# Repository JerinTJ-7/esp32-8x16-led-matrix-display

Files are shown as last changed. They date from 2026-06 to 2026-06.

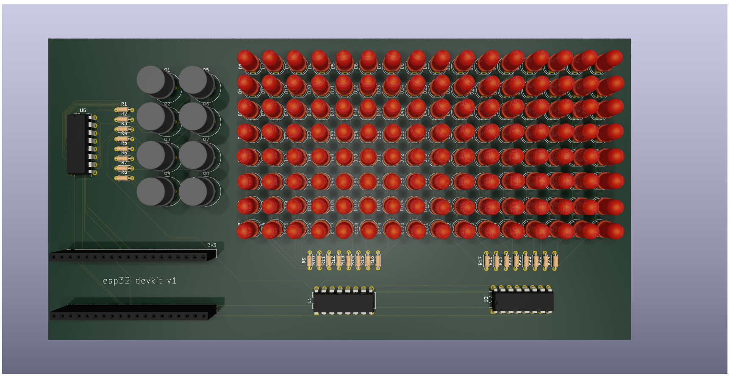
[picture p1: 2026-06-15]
Images/led display pcb2.png

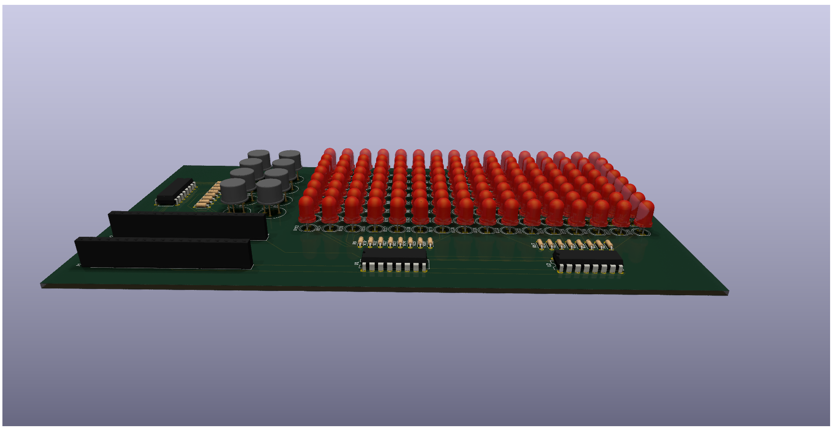
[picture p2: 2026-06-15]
Images/led display pcb3.png

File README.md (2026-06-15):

# ESP32 8×16 LED Matrix Display Board

## Overview

This project is a custom PCB-based LED matrix display designed using KiCad.

The system uses:
- ESP32 DevKit V1
- 74HC595 Shift Registers
- LED Matrix (8×16)
- Blynk IoT
- Wokwi Simulation

## Features

- Text display
- Scrolling messages
- Wi-Fi connectivity
- Mobile control using Blynk
- Custom KiCad PCB

## Tools Used

- KiCad 9
- Arduino IDE
- Wokwi Simulator
- Blynk IoT

## Images
led display pcb

## Files

- KiCad Design Files
- Gerbers
- BOM
- Arduino Firmware
- Project Report

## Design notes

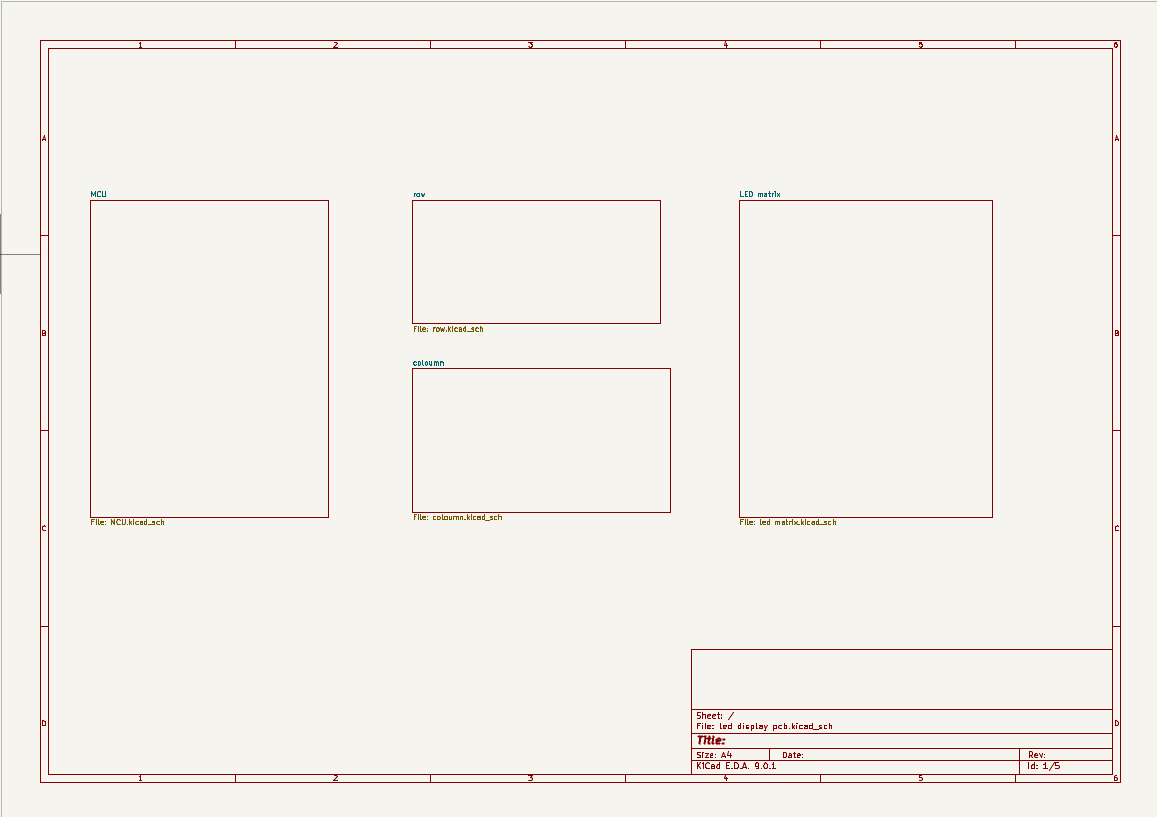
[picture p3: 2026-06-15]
Images/schematic.png

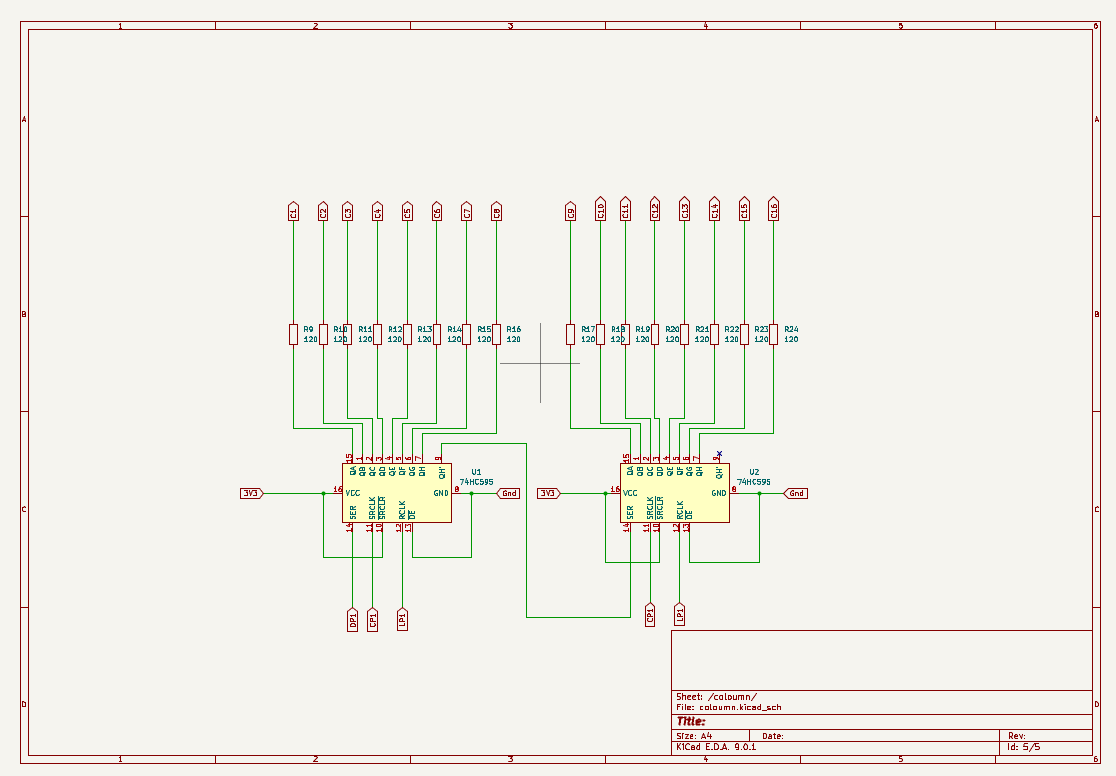
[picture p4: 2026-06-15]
Images/schematic_column.png

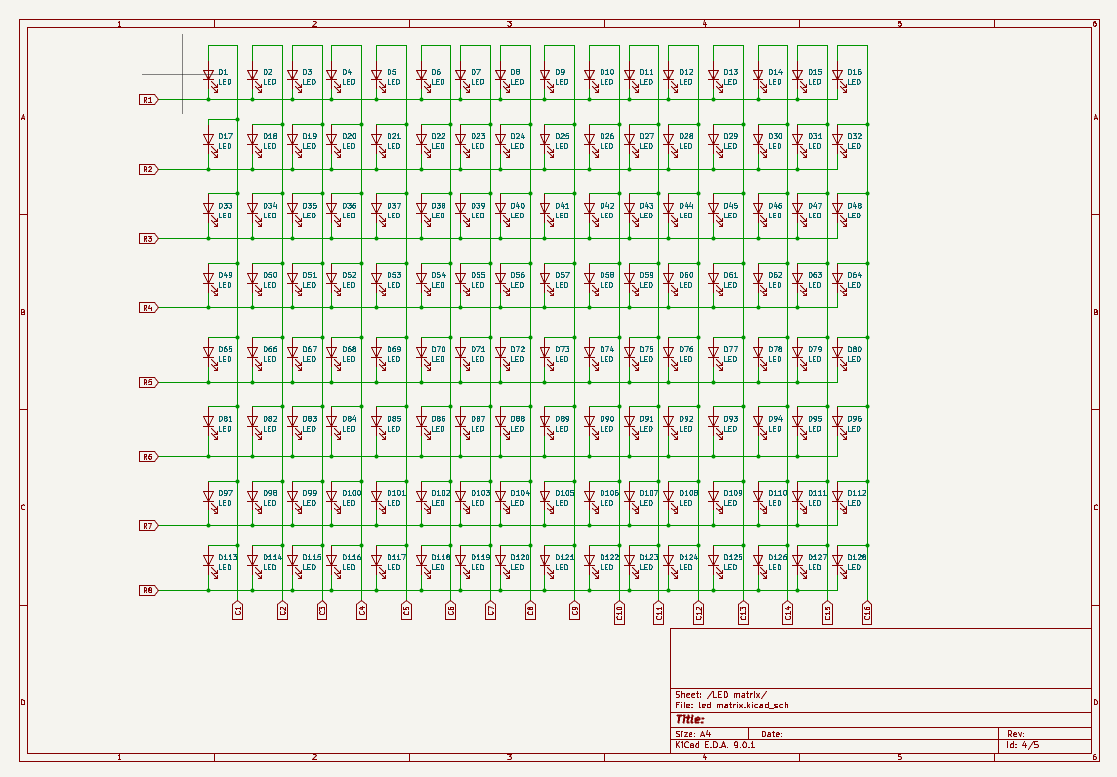
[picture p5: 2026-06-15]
Images/schematic_LED Matrix.png

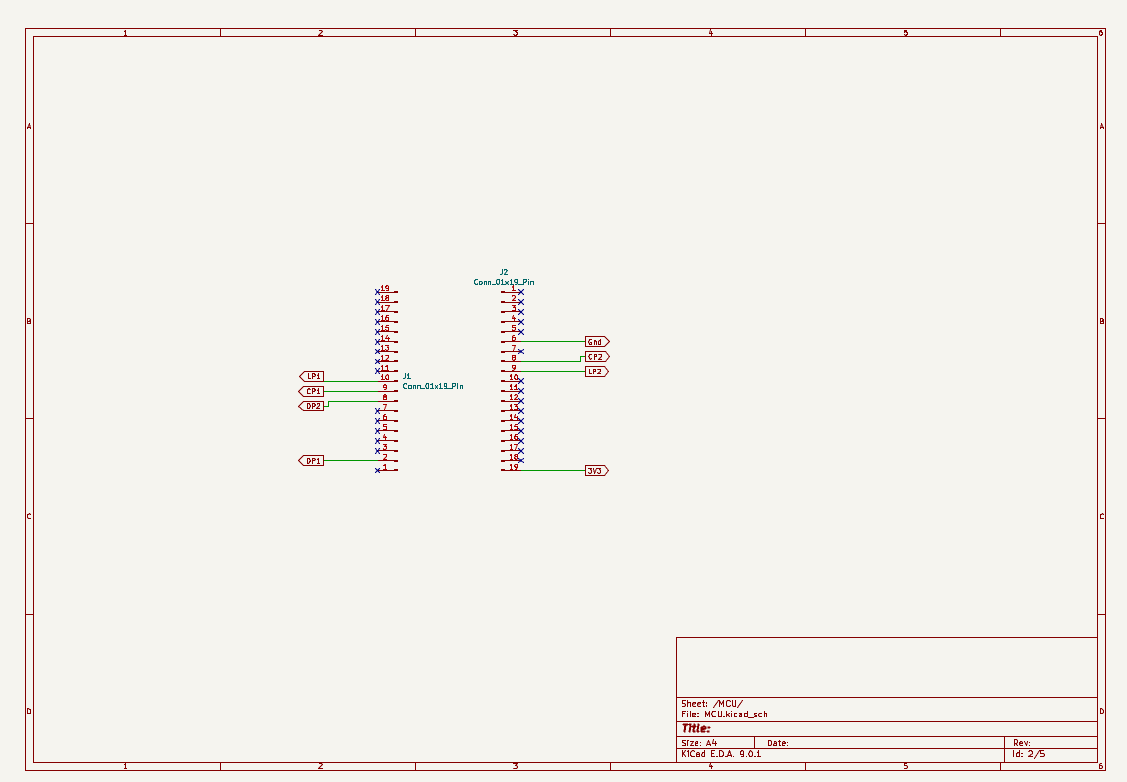
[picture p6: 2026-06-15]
Images/schematic_mcu.png

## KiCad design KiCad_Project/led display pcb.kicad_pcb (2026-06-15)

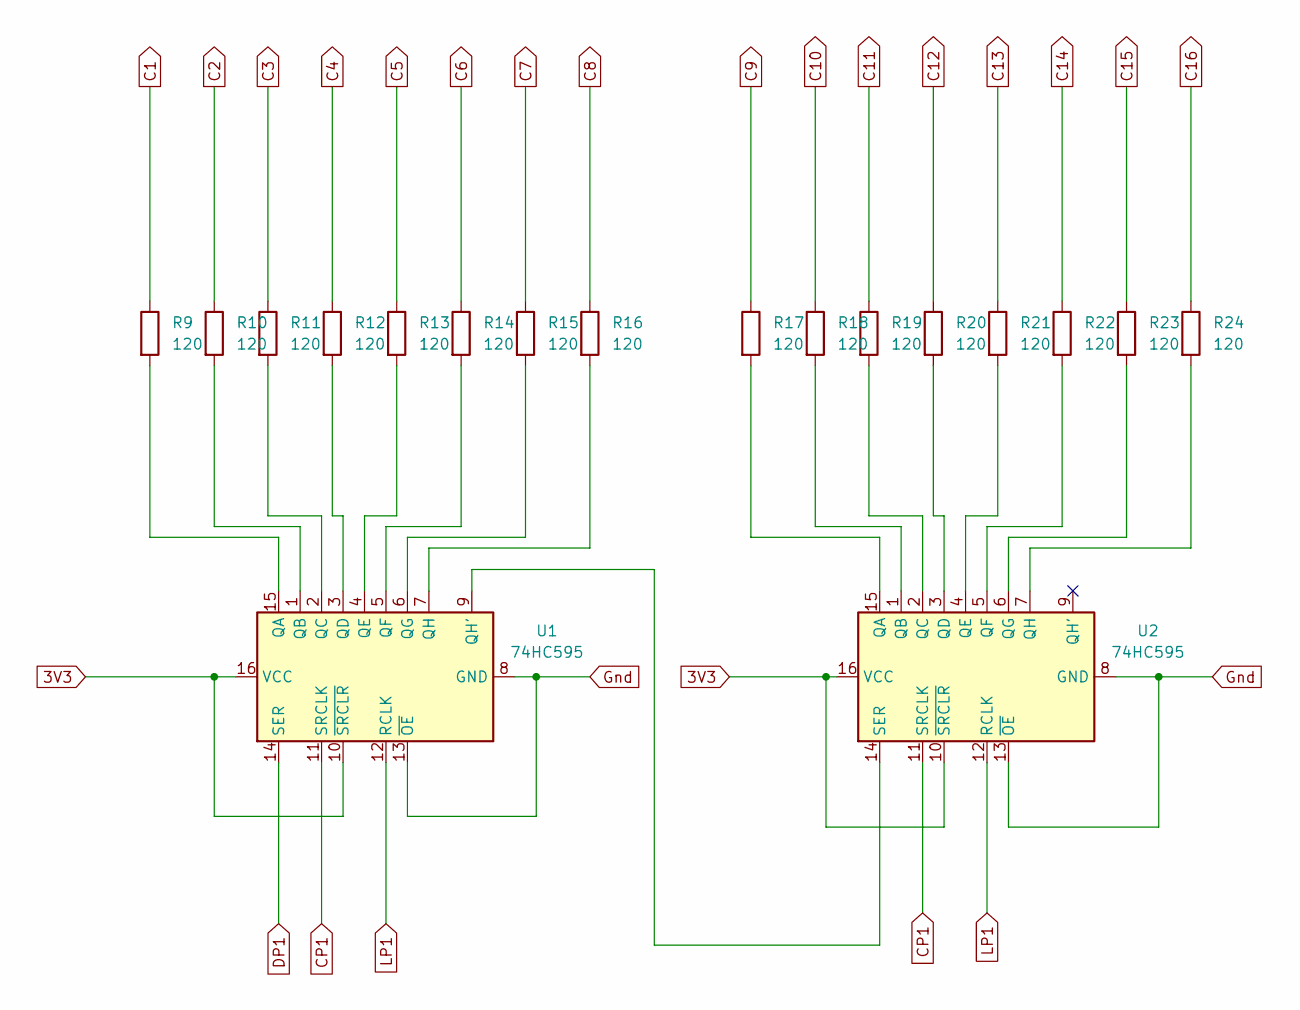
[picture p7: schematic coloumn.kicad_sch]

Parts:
R9, R10, R11, R12, R13, R14, R15, R16, R17, R18, R19, R20, R21, R22, R23, R24: 120; R_Axial_DIN0204_L3.6mm_D1.6mm_P5.08mm_Horizontal
U1, U2: 74HC595; DIP-16_W7.62mm

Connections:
3V3: U1.10 (~SRCLR), U1.16 (VCC), U2.10 (~SRCLR), U2.16 (VCC); also elsewhere on the board
C1: R9.1; also elsewhere on the board
C2: R10.1; also elsewhere on the board
C3: R11.1; also elsewhere on the board
C4: R12.1; also elsewhere on the board
C5: R13.1; also elsewhere on the board
C6: R14.1; also elsewhere on the board
C7: R15.1; also elsewhere on the board
C8: R16.1; also elsewhere on the board
C9: R17.1; also elsewhere on the board
C10: R18.1; also elsewhere on the board
C11: R19.1; also elsewhere on the board
C12: R20.1; also elsewhere on the board
C13: R21.1; also elsewhere on the board
C14: R22.1; also elsewhere on the board
C15: R23.1; also elsewhere on the board
C16: R24.1; also elsewhere on the board
CP1: U1.11 (SRCLK), U2.11 (SRCLK); also elsewhere on the board
DP1: U1.14 (SER); also elsewhere on the board
Gnd: U1.8 (GND), U1.13 (~OE), U2.8 (GND), U2.13 (~OE); also elsewhere on the board
LP1: U1.12 (RCLK), U2.12 (RCLK); also elsewhere on the board
unnamed: R9.2, U1.15 (QA)
unnamed: R10.2, U1.1 (QB)
unnamed: R11.2, U1.2 (QC)
unnamed: R12.2, U1.3 (QD)
unnamed: R13.2, U1.4 (QE)
unnamed: R14.2, U1.5 (QF)
unnamed: R15.2, U1.6 (QG)
unnamed: U1.9 (QH'), U2.14 (SER)
unnamed: R16.2, U1.7 (QH)
unnamed: R17.2, U2.15 (QA)
unnamed: R18.2, U2.1 (QB)
unnamed: R19.2, U2.2 (QC)
unnamed: R20.2, U2.3 (QD)
unnamed: R21.2, U2.4 (QE)
unnamed: R22.2, U2.5 (QF)
unnamed: R23.2, U2.6 (QG)
unnamed: R24.2, U2.7 (QH)

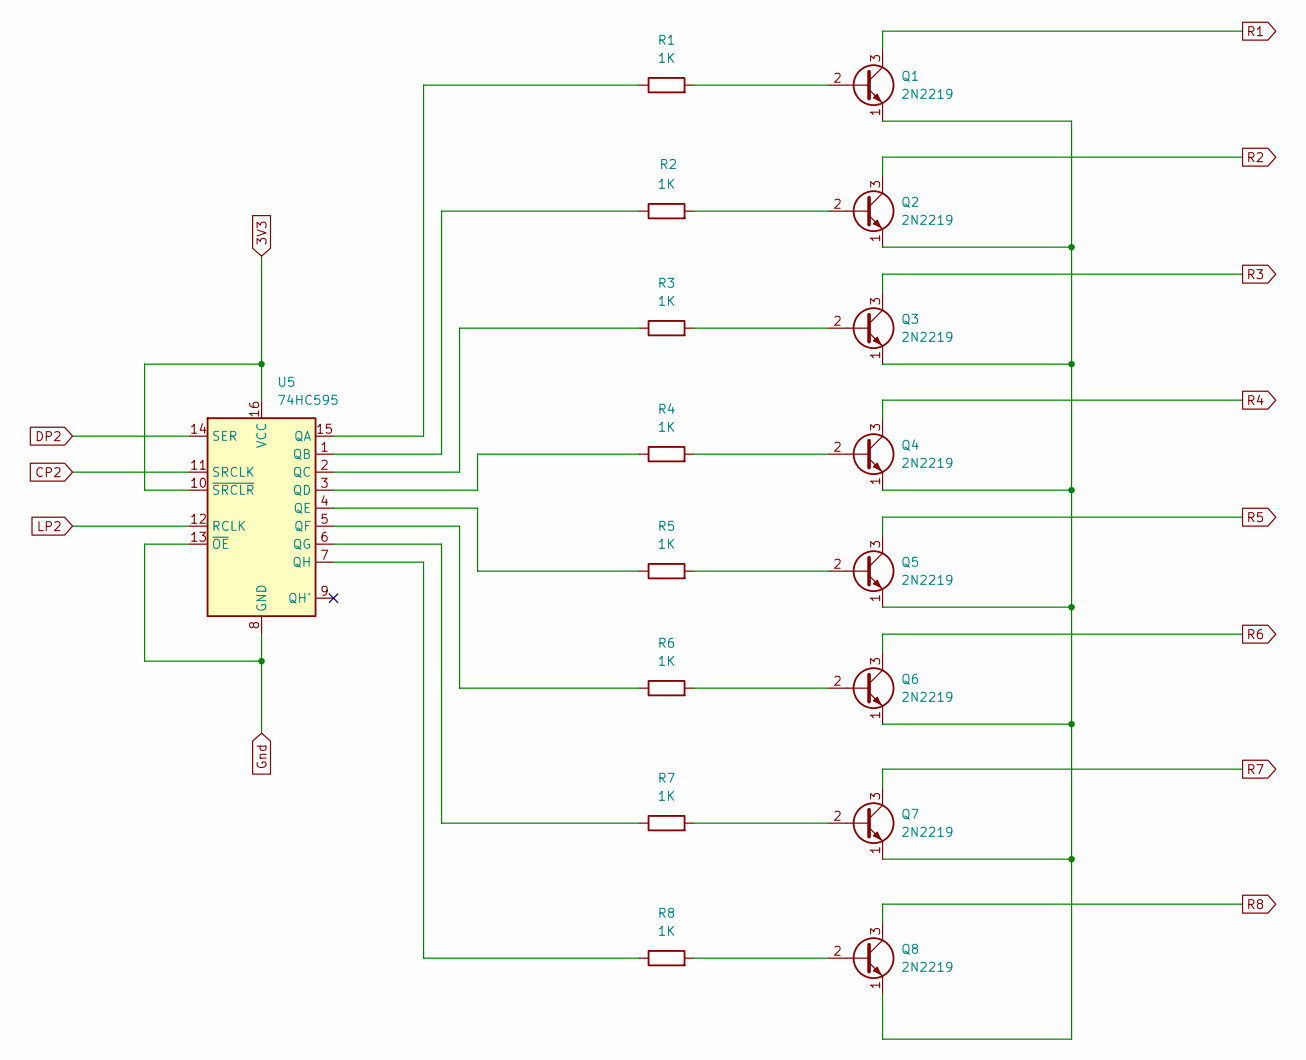
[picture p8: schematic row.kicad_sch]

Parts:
Q1, Q2, Q3, Q4, Q5, Q6, Q7, Q8: 2N2219; TO-39-3
R1, R2, R3, R4, R5, R6, R7, R8: 1K; R_Axial_DIN0204_L3.6mm_D1.6mm_P5.08mm_Horizontal
U5: 74HC595; DIP-16_W7.62mm

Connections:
3V3: U5.10 (~SRCLR), U5.16 (VCC); also elsewhere on the board
CP2: U5.11 (SRCLK); also elsewhere on the board
DP2: U5.14 (SER); also elsewhere on the board
Gnd: U5.8 (GND), U5.13 (~OE); also elsewhere on the board
LP2: U5.12 (RCLK); also elsewhere on the board
unnamed: Q1.2 (B), R1.2
unnamed: Q1.1 (E), Q2.1 (E), Q3.1 (E), Q4.1 (E), Q5.1 (E), Q6.1 (E), Q7.1 (E), Q8.1 (E)
unnamed: Q2.2 (B), R2.2
unnamed: Q3.2 (B), R3.2
unnamed: Q4.2 (B), R4.2
unnamed: Q5.2 (B), R5.2
unnamed: Q6.2 (B), R6.2
unnamed: Q7.2 (B), R7.2
unnamed: Q8.2 (B), R8.2
unnamed: R1.1, U5.15 (QA)
unnamed: R2.1, U5.1 (QB)
unnamed: R3.1, U5.2 (QC)
unnamed: R4.1, U5.3 (QD)
unnamed: R5.1, U5.4 (QE)
unnamed: R6.1, U5.5 (QF)
unnamed: R7.1, U5.6 (QG)
unnamed: R8.1, U5.7 (QH)
R1: Q1.3 (C); also elsewhere on the board
R2: Q2.3 (C); also elsewhere on the board
R3: Q3.3 (C); also elsewhere on the board
R4: Q4.3 (C); also elsewhere on the board
R5: Q5.3 (C); also elsewhere on the board
R6: Q6.3 (C); also elsewhere on the board
R7: Q7.3 (C); also elsewhere on the board
R8: Q8.3 (C); also elsewhere on the board

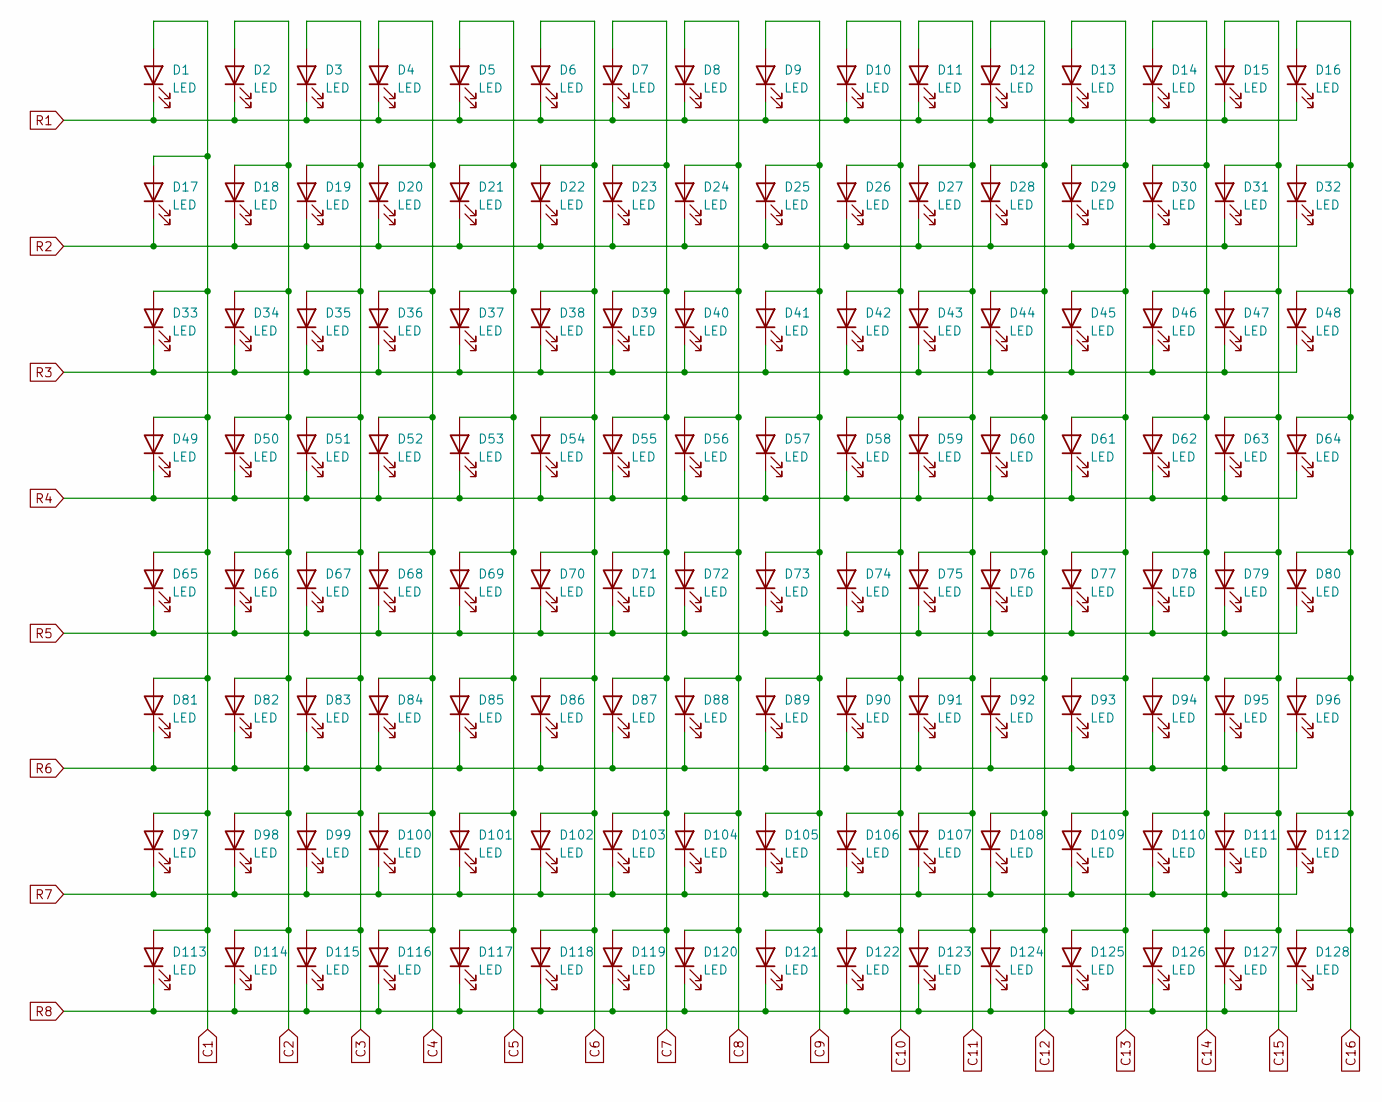
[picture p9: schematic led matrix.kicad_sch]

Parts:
D1, D2, D3, D4, D5, D6, D7, D8, D9, D10, D11, D12, D13, D14, D15, D16, D17, D18, D19, D20, D21, D22, D23, D24, D25, D26, D27, D28, D29, D30, D31, D32, D33, D34, D35, D36, D37, D38, D39, D40, D41, D42, D43, D44, D45, D46, D47, D48, D49, D50, D51, D52, D53, D54, D55, D56, D57, D58, D59, D60, D61, D62, D63, D64, D65, D66, D67, D68, D69, D70, D71, D72, D73, D74, D75, D76, D77, D78, D79, D80, D81, D82, D83, D84, D85, D86, D87, D88, D89, D90, D91, D92, D93, D94, D95, D96, D97, D98, D99, D100, D101, D102, D103, D104, D105, D106, D107, D108, D109, D110, D111, D112, D113, D114, D115, D116, D117, D118, D119, D120, D121, D122, D123, D124, D125, D126, D127, D128: LED; LED_D5.0mm

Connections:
C1: D1.2 (A), D17.2 (A), D33.2 (A), D49.2 (A), D65.2 (A), D81.2 (A), D97.2 (A), D113.2 (A); also elsewhere on the board
C2: D2.2 (A), D18.2 (A), D34.2 (A), D50.2 (A), D66.2 (A), D82.2 (A), D98.2 (A), D114.2 (A); also elsewhere on the board
C3: D3.2 (A), D19.2 (A), D35.2 (A), D51.2 (A), D67.2 (A), D83.2 (A), D99.2 (A), D115.2 (A); also elsewhere on the board
C4: D4.2 (A), D20.2 (A), D36.2 (A), D52.2 (A), D68.2 (A), D84.2 (A), D100.2 (A), D116.2 (A); also elsewhere on the board
C5: D5.2 (A), D21.2 (A), D37.2 (A), D53.2 (A), D69.2 (A), D85.2 (A), D101.2 (A), D117.2 (A); also elsewhere on the board
C6: D6.2 (A), D22.2 (A), D38.2 (A), D54.2 (A), D70.2 (A), D86.2 (A), D102.2 (A), D118.2 (A); also elsewhere on the board
C7: D7.2 (A), D23.2 (A), D39.2 (A), D55.2 (A), D71.2 (A), D87.2 (A), D103.2 (A), D119.2 (A); also elsewhere on the board
C8: D8.2 (A), D24.2 (A), D40.2 (A), D56.2 (A), D72.2 (A), D88.2 (A), D104.2 (A), D120.2 (A); also elsewhere on the board
C9: D9.2 (A), D25.2 (A), D41.2 (A), D57.2 (A), D73.2 (A), D89.2 (A), D105.2 (A), D121.2 (A); also elsewhere on the board
C10: D10.2 (A), D26.2 (A), D42.2 (A), D58.2 (A), D74.2 (A), D90.2 (A), D106.2 (A), D122.2 (A); also elsewhere on the board
C11: D11.2 (A), D27.2 (A), D43.2 (A), D59.2 (A), D75.2 (A), D91.2 (A), D107.2 (A), D123.2 (A); also elsewhere on the board
C12: D12.2 (A), D28.2 (A), D44.2 (A), D60.2 (A), D76.2 (A), D92.2 (A), D108.2 (A), D124.2 (A); also elsewhere on the board
C13: D13.2 (A), D29.2 (A), D45.2 (A), D61.2 (A), D77.2 (A), D93.2 (A), D109.2 (A), D125.2 (A); also elsewhere on the board
C14: D14.2 (A), D30.2 (A), D46.2 (A), D62.2 (A), D78.2 (A), D94.2 (A), D110.2 (A), D126.2 (A); also elsewhere on the board
C15: D15.2 (A), D31.2 (A), D47.2 (A), D63.2 (A), D79.2 (A), D95.2 (A), D111.2 (A), D127.2 (A); also elsewhere on the board
C16: D16.2 (A), D32.2 (A), D48.2 (A), D64.2 (A), D80.2 (A), D96.2 (A), D112.2 (A), D128.2 (A); also elsewhere on the board
R1: D1.1 (K), D2.1 (K), D3.1 (K), D4.1 (K), D5.1 (K), D6.1 (K), D7.1 (K), D8.1 (K), D9.1 (K), D10.1 (K), D11.1 (K), D12.1 (K), D13.1 (K), D14.1 (K), D15.1 (K), D16.1 (K); also elsewhere on the board
R2: D17.1 (K), D18.1 (K), D19.1 (K), D20.1 (K), D21.1 (K), D22.1 (K), D23.1 (K), D24.1 (K), D25.1 (K), D26.1 (K), D27.1 (K), D28.1 (K), D29.1 (K), D30.1 (K), D31.1 (K), D32.1 (K); also elsewhere on the board
R3: D33.1 (K), D34.1 (K), D35.1 (K), D36.1 (K), D37.1 (K), D38.1 (K), D39.1 (K), D40.1 (K), D41.1 (K), D42.1 (K), D43.1 (K), D44.1 (K), D45.1 (K), D46.1 (K), D47.1 (K), D48.1 (K); also elsewhere on the board
R4: D49.1 (K), D50.1 (K), D51.1 (K), D52.1 (K), D53.1 (K), D54.1 (K), D55.1 (K), D56.1 (K), D57.1 (K), D58.1 (K), D59.1 (K), D60.1 (K), D61.1 (K), D62.1 (K), D63.1 (K), D64.1 (K); also elsewhere on the board
R5: D65.1 (K), D66.1 (K), D67.1 (K), D68.1 (K), D69.1 (K), D70.1 (K), D71.1 (K), D72.1 (K), D73.1 (K), D74.1 (K), D75.1 (K), D76.1 (K), D77.1 (K), D78.1 (K), D79.1 (K), D80.1 (K); also elsewhere on the board
R6: D81.1 (K), D82.1 (K), D83.1 (K), D84.1 (K), D85.1 (K), D86.1 (K), D87.1 (K), D88.1 (K), D89.1 (K), D90.1 (K), D91.1 (K), D92.1 (K), D93.1 (K), D94.1 (K), D95.1 (K), D96.1 (K); also elsewhere on the board
R7: D97.1 (K), D98.1 (K), D99.1 (K), D100.1 (K), D101.1 (K), D102.1 (K), D103.1 (K), D104.1 (K), D105.1 (K), D106.1 (K), D107.1 (K), D108.1 (K), D109.1 (K), D110.1 (K), D111.1 (K), D112.1 (K); also elsewhere on the board
R8: D113.1 (K), D114.1 (K), D115.1 (K), D116.1 (K), D117.1 (K), D118.1 (K), D119.1 (K), D120.1 (K), D121.1 (K), D122.1 (K), D123.1 (K), D124.1 (K), D125.1 (K), D126.1 (K), D127.1 (K), D128.1 (K); also elsewhere on the board

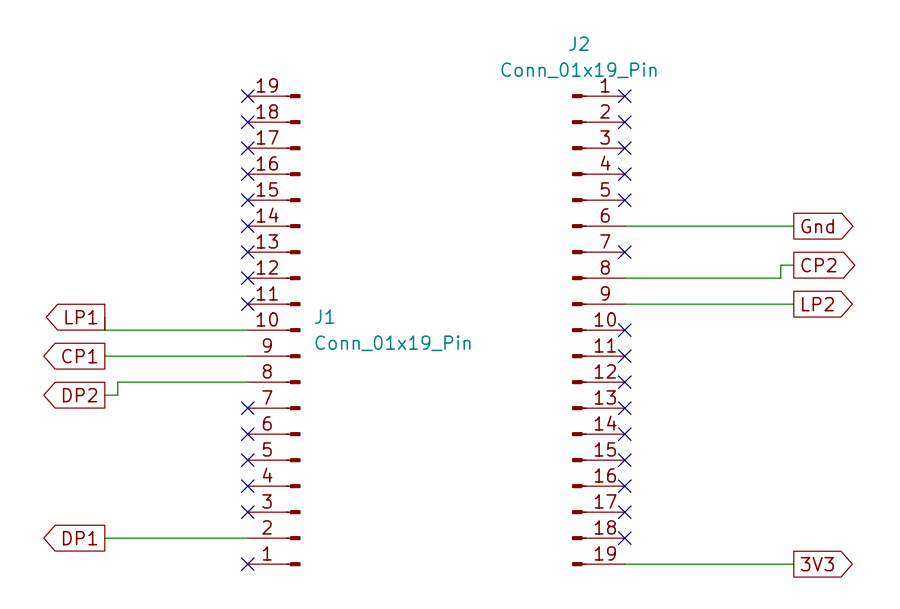
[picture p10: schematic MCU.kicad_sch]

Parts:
J1, J2: Conn_01x19_Pin; PinSocket_1x19_P2.54mm_Vertical

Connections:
3V3: J2.19; also elsewhere on the board
CP1: J1.9; also elsewhere on the board
CP2: J2.8; also elsewhere on the board
DP1: J1.2; also elsewhere on the board
DP2: J1.8; also elsewhere on the board
Gnd: J2.6; also elsewhere on the board
LP1: J1.10; also elsewhere on the board
LP2: J2.9; also elsewhere on the board

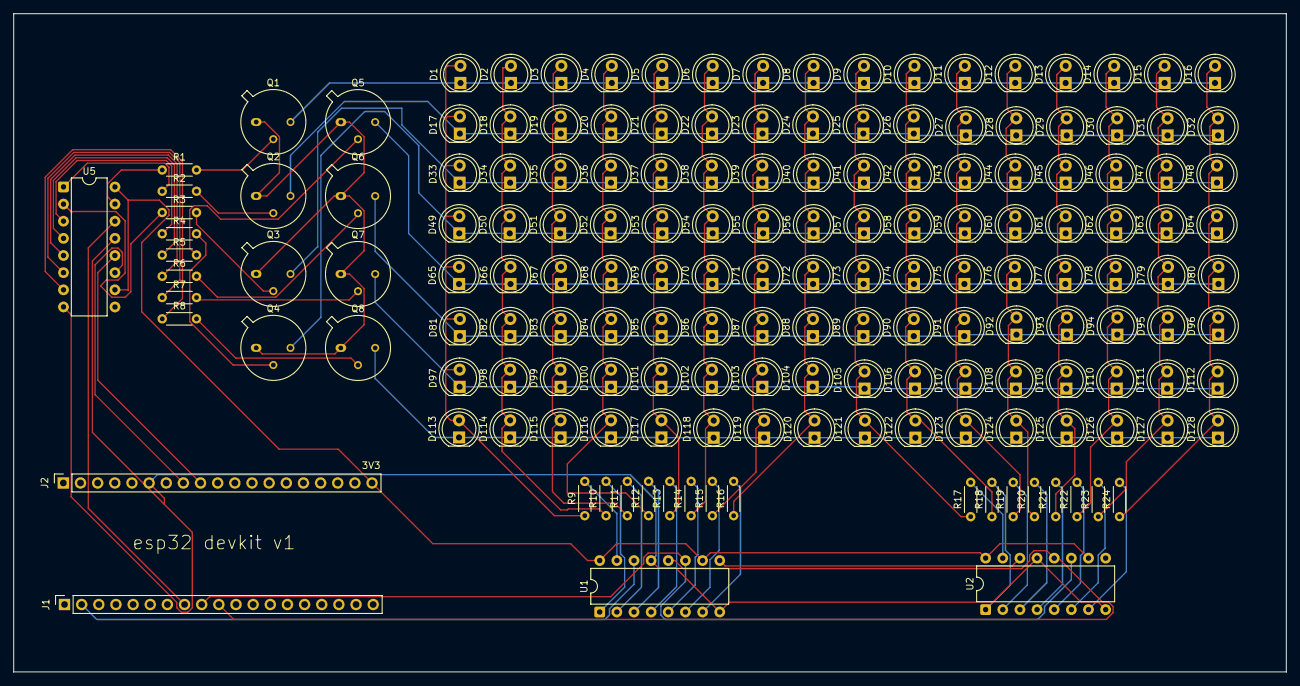
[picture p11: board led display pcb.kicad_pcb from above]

Board: 2 copper layers, 188.5 x 97.5 mm, 165 parts (0 on the bottom side), 66 nets.

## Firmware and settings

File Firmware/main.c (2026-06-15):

////////////////using blynk////////////////////////////

#define BLYNK_PRINT Serial
#include <WiFi.h>
// #include <arduino.h>

//-------- Blynk Credentials --------
#define BLYNK_TEMPLATE_ID " BLYNK_TEMPLATE_ID"
#define BLYNK_TEMPLATE_NAME "BLYNK_TEMPLATE_NAME "
#define BLYNK_DEVICE_NAME " BLYNK_DEVICE_NAME"
#define BLYNK_AUTH_TOKEN " BLYNK_AUTH_TOKEN"

#include <BlynkSimpleEsp32.h>

//-------- WiFi Credentials --------
char ssid[] = "Wokwi-GUEST";
char pass[] = "";

//-------- Variables --------
#define MAX_BINARY_COLS 64
byte binaryCols[MAX_BINARY_COLS];
int binaryColCount = 0;
bool binaryMode = false;
bool textmode = true;
bool displayEnabled = false;
String msg = "HELLO ";
int scrollspeed = 15;
bool msg_changed = false;

// Columns(anodes)
int clockPin1 = 18;
int latchPin1 = 5;
int dataPin1 = 23;

// Rows(cathodes)
int clockPin2 = 14;
int latchPin2 = 27;
int dataPin2 = 19;

// BITMAP
byte bitmap[8][2];
int numZones = sizeof(bitmap) / 8; // one zone=8X8 matrix
int maxZoneIndex = numZones - 1;
int numCols = numZones * 8;

int refresh_time = 300;

// FONT
byte alphabets[][8] = {
    {0, 0, 0, 0, 0}, //@ as SPACE
    //{8,28,54,99,65},//<<
    {31, 36, 68, 36, 31},   // A
    {127, 73, 73, 73, 54},  // B
    {62, 65, 65, 65, 34},   // C
    {127, 65, 65, 34, 28},  // D
    {127, 73, 73, 65, 65},  // E
    {127, 72, 72, 72, 64},  // F
    {62, 65, 65, 69, 38},   // G
    {127, 8, 8, 8, 127},    // H
    {0, 65, 127, 65, 0},    // I
    {2, 1, 1, 1, 126},      // J
    {127, 8, 20, 34, 65},   // K
    {127, 1, 1, 1, 1},      // L
    {127, 32, 16, 32, 127}, // M
    {127, 32, 16, 8, 127},  // N
    {62, 65, 65, 65, 62},   // O
    {127, 72, 72, 72, 48},  // P
    {62, 65, 69, 66, 61},   // Q
    {127, 72, 76, 74, 49},  // R
    {50, 73, 73, 73, 38},   // S
    {64, 64, 127, 64, 64},  // T
    {126, 1, 1, 1, 126},    // U
    {124, 2, 1, 2, 124},    // V
    {126, 1, 6, 1, 126},    // W
    {99, 20, 8, 20, 99},    // X
    {96, 16, 15, 16, 96},   // Y
    {67, 69, 73, 81, 97},   // Z
};

// Clear bitmap
void clear()
{
  for (int row = 0; row < 8; row++)
  {
    for (int zone = 0; zone <= maxZoneIndex; zone++)
    {
      bitmap[row][zone] = 0;
    }
  }
}

void on()
{
  for (int row = 0; row < 8; row++)
  {
    for (int zone = 0; zone <= maxZoneIndex; zone++)
    {
      bitmap[row][zone] = 0xFF;
    }
  }
}

// Displays bitmap array in the matrix
void RefreshDisplay()
{
  for (int row = 0; row < 8; row++)
  { // blank all rows
    digitalWrite(latchPin2, LOW);
    shiftOut(dataPin2, clockPin2, MSBFIRST, 0xFF);
    digitalWrite(latchPin2, HIGH);

    int rowbit = 1 << row;
    digitalWrite(latchPin2, LOW); // for transmitting data
    shiftOut(dataPin2, clockPin2, MSBFIRST, ~rowbit);

    // Start sending column bytes
    digitalWrite(latchPin1, LOW);

    // Shift out to each matrix
    for (int zone = maxZoneIndex; zone >= 0; zone--)
    {
      shiftOut(dataPin1, clockPin1, MSBFIRST, bitmap[row][zone]);
    }
    digitalWrite(latchPin1, HIGH);
    digitalWrite(latchPin2, HIGH);
    delayMicroseconds(refresh_time);
  }
}

//-------- Blynk Text Input --------
BLYNK_WRITE(V1)
{
  clear();
  RefreshDisplay();
  binaryMode = false;
  textmode = true;
  scrollspeed = 15;
  refresh_time = 300;
  msg = param.asStr();
  msg.toUpperCase();
  msg += " ";
  msg_changed = true;
}

void setup()
{
  pinMode(latchPin1, OUTPUT);
  pinMode(clockPin1, OUTPUT);
  pinMode(dataPin1, OUTPUT);
  pinMode(latchPin2, OUTPUT);
  pinMode(clockPin2, OUTPUT);
  pinMode(dataPin2, OUTPUT);
  Serial.begin(115200);
  Blynk.begin(BLYNK_AUTH_TOKEN, ssid, pass);
  clear();
}

void parseBinaryText(String input)
{
  input.replace(" ", "");
  input.replace("\n", ",");
  String rows[8];
  int rowCount = 0;
  int start = 0;

  // Split rows
  while (rowCount < 8)
  {
    int comma = input.indexOf(',', start);
    if (comma == -1)
      rows[rowCount++] = input.substring(start);
    else
      rows[rowCount++] = input.substring(start, comma);

    if (comma == -1)
      break;
    start = comma + 1;
  }

  if (rowCount != 8)
    return;

  int cols = rows[0].length();
  if (cols > MAX_BINARY_COLS)
    cols = MAX_BINARY_COLS;

  binaryColCount = cols;

  // Convert rows → columns
  for (int col = 0; col < cols; col++)
  {
    byte value = 0;
    for (int row = 0; row < 8; row++)
    {
      if (rows[row].charAt(col) == '1')
        bitSet(value, 7 - row);
    }
    binaryCols[col] = value;
  }

  binaryMode = true;
  textmode = false;
  msg_changed = true;
}

//---------Blynk binary no. input----------
BLYNK_WRITE(V2)
{
  String input = param.asStr();
  parseBinaryText(input);
  msg_changed = true;
  textmode = false;
  binaryMode = true;
  clear();
  RefreshDisplay();
  scrollspeed = 22;
  refresh_time = 700;
}

//-------- Blynk Slider (Scroll Speed) --------
BLYNK_WRITE(V3)
{
  scrollspeed = 56 - param.asInt();
}

// Converts row and colum to bitmap bit and turn it off/on
void Plot(int col, int row, bool isOn)
{
  int zone = col / 8;
  int colBitIndex = col % 8;
  byte colBit = 1 << colBitIndex;
  if (isOn)
    bitmap[row][zone] = bitmap[row][zone] | colBit;
  else
    bitmap[row][zone] = bitmap[row][zone] & (~colBit);
}

//-------- Blynk Button (ON/OFF) --------
bool started = false;
BLYNK_WRITE(V0)
{
  displayEnabled = param.asInt();

  if (!displayEnabled)
  {
    started = false;
    clear();
    RefreshDisplay();
  }
  else
  {
    if (!started)
    {
      started = true;
      refresh_time = 100;
      scrollspeed = 10;
      clear();
      for (int row = 0; row < 8; row++)
      {
        for (int col = 0; col < numCols; col++)
        {
          Plot(col, row, true);
        }
        for (int i = 0; i < 50; i++)
          RefreshDisplay();
      }
      refresh_time = 300;
      for (int i = 0; i < 4; i++)
      {
        on();
        for (int refreshCount = 0; refreshCount < 30; refreshCount++)
          RefreshDisplay();

        clear();
        for (int refreshCount = 0; refreshCount < 30; refreshCount++)
          RefreshDisplay();
      }
    }
  }
}

// Plot each character of the message one column at a time, updated the display, shift bitmap left.
void XProcess()
{
  if (binaryMode)
  {
    int binarycol = binaryColCount;
    // Draw one character of the message
    for (int col = 0; col < binarycol; col++)
    {
      for (int row = 0; row < 8; row++)
      {
        bool isOn = 0;
        if (col < binarycol)
          isOn = bitRead(binaryCols[col], 7 - row) == 1;
        Plot(numCols - 1, row, isOn); // Draw on the rightmost column, the shift loop below will scroll it leftward.
      }
      for (int refreshCount = 0; refreshCount < scrollspeed; refreshCount++)
        RefreshDisplay();
      // Shift the bitmap one column to left
      for (int row = 0; row < 8; row++)
      {
        for (int zone = 0; zone < numZones; zone++)
        {
          // This right shift would show as a left scroll on display because leftmost column is represented by least significant bit of the byte.
          bitmap[row][zone] = bitmap[row][zone] >> 1;
          // Shift over lowest bit from the next zone as highest bit of this zone.
          if (zone < maxZoneIndex)
            bitWrite(bitmap[row][zone], 7, bitRead(bitmap[row][zone + 1], 0));
        }
      }
      msg_changed = false;
      Blynk.run();
      if (msg_changed || !displayEnabled)
      {
        on();
        for (int refreshCount = 0; refreshCount < 100; refreshCount++)
          RefreshDisplay();
        clear();
        for (int refreshCount = 0; refreshCount < 30; refreshCount++)
          RefreshDisplay();
        msg_changed = false;
        break;
      }
    }
  }

  if (textmode)
  {
    for (int charIndex = 0; charIndex < msg.length(); charIndex++)
    {
      int alphabetIndex = msg[charIndex] - '@';
      if (alphabetIndex < 0)
        alphabetIndex = 0;
      int binarycol = sizeof(alphabets[alphabetIndex]);
      // Draw one character of the message
      for (int col = 0; col < binarycol; col++)
      {
        for (int row = 0; row < 8; row++)
        {
          bool isOn = 0;
          if (col < binarycol)
            isOn = bitRead(alphabets[alphabetIndex][col], 7 - row) == 1;
          Plot(numCols - 1, row, isOn); // Draw on the rightmost column, the shift loop below will scroll it leftward.
        }
        for (int refreshCount = 0; refreshCount < scrollspeed; refreshCount++)
          RefreshDisplay();
        // Shift the bitmap one column to left
        for (int row = 0; row < 8; row++)
        {
          for (int zone = 0; zone < numZones; zone++)
          {
            // This right shift would show as a left scroll on display because leftmost column is represented by least significant bit of the byte.
            bitmap[row][zone] = bitmap[row][zone] >> 1;
            // Shift over lowest bit from the next zone as highest bit of this zone.
            if (zone <= maxZoneIndex)
              bitWrite(bitmap[row][zone], 7, bitRead(bitmap[row][zone + 1], 0));
          }
        }
      }
      msg_changed = false;
      Blynk.run();
      if (msg_changed || !displayEnabled)
      {
        on();
        for (int refreshCount = 0; refreshCount < 100; refreshCount++)
          RefreshDisplay();
        clear();
        for (int refreshCount = 0; refreshCount < 30; refreshCount++)
          RefreshDisplay();
        msg_changed = false;
        break;
      }
    }
  }
}

void loop()
{
  Blynk.run();
  if (displayEnabled)
  {
    XProcess();
  }
}
